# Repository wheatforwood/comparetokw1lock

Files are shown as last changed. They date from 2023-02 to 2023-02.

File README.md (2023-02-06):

A 3D printable lock that is compatible with mass-produced KW1 locks. It is accurate enough to interchange parts.

An SLA printer will be required to hit acceptable tolerances. You will need springs, top pins and bottom pins for your chambers. Finally, you will need a retaining clip to hold the plug in the bible and will most likly need to use a Q-Tip to clean excess resin from the top of the chamber via the access ports in the bottom of the bible. This model is for educational and prototyping purposes, it was not designed for field use. Use at your own risk!

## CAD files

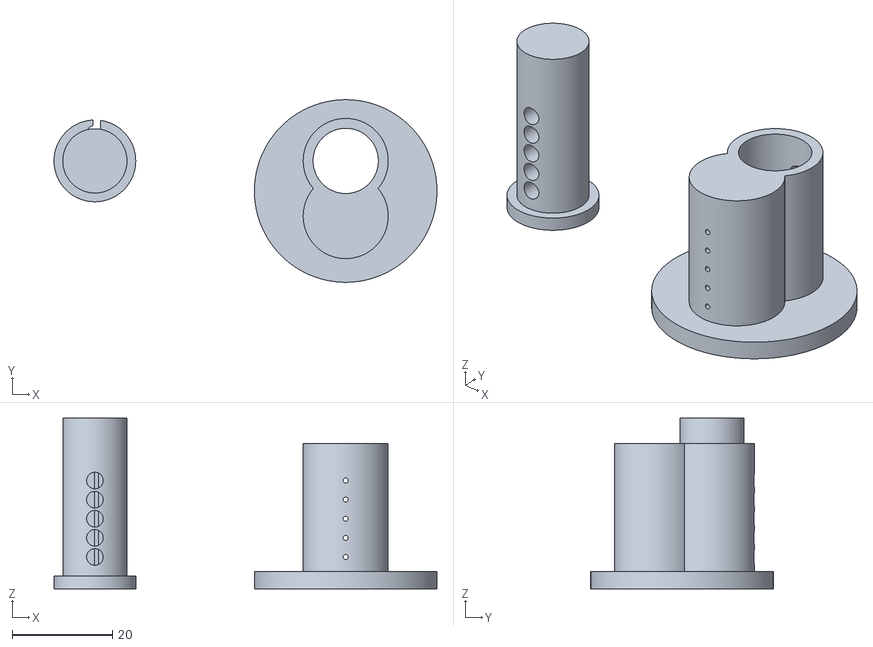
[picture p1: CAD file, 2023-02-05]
comparetokw1Lock.stl
76.3 x 36.4 x 34.0

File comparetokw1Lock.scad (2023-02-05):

$fn = 365;
// tollerance
$tol = 0.05;
// How many chambers are there in the lock to hold pins?
$number_chambers = 5;
// distance from 0 to the start of the first pin
$first_pin_offset = 6.34;
// distace between each pin chamber in the plug/bible
$chamber_dist = 3.81;
// the diameter of the chambers
$chamber_dia = 3.31;

$plug_diamater = 12.8;
$plug_rim_dia = $plug_diamater + 3.5;
$plug_length = 34;

$bible_thickness = 2;
$keyway_length =  28;
$keyway_height = 11.3;
$keyway_width = 3;
$keyway_offset_from_top_plug_rim = 5.5;

module compare_to_kw1_plug(){
    difference() {
        // additive
        union() {
            cylinder(d1=$plug_diamater, d2=$plug_diamater, h=$plug_length);
            cylinder(d1=$plug_rim_dia, d2=$plug_rim_dia, h=2.5);
        }
        
        //substractive
        union() {
            // chamber holes
            for ( i = [0 : ($number_chambers - 1)] ){
                translate([0,.80,($first_pin_offset + ($chamber_dist*i))]) {
                    rotate([90, 0 , 0]){
                        cylinder(d1=$chamber_dia, d2=$chamber_dia, h=30);
                    }
                }
            }
            // front concave
            translate([0,1.6,-11]){
                sphere(d=25);
            }
            
            //keyway
            // the .39 is a correction after printing and testing lock
            rotate([180,0,0]){
                translate([-$keyway_width/2, ( ($keyway_height * -1) + ($plug_rim_dia /2) +.39) - $keyway_offset_from_top_plug_rim, -$keyway_length]){
                        linear_extrude(height =$keyway_length) import("keyway.svg");
                }
            }
        }
    }
}

module compare_to_kw1_bible(){
    difference() {
        //additive
        union(){
            translate([0,-6,0]){
                cylinder(d1= 36.4, d2=36.4, h=3.4);
            }
            translate([0,0,3.3]){
                cylinder(d1=$plug_diamater+$tol+4.09, d2=$plug_diamater+$tol+4.09, $plug_length-8.3);
            }
            translate([0,-11,3.3]){
                cylinder(d1=$plug_diamater+$tol+4.09, d2=$plug_diamater+$tol+4.09, $plug_length-8.3);
            }
        }
        //subtractive
        union() {
            translate([9,-7.75,-2]){
            rotate([0, 0, 180]) {
            linear_extrude(height =2.5) resize([0,10,0], auto=true) import("WheatForWoodMark.svg");
            }
        }
            // chamber holes
            for ( i = [0 : ($number_chambers-1)] ){
                translate([0,.80,($first_pin_offset + ($chamber_dist*i))]) {
                    rotate([90, 0 , 0]){
                        cylinder(d1=$chamber_dia, d2=$chamber_dia, h=18.8);
                    }
                }
            }
            
            // vent holes for chambers (to prevent top pins getting stuck issue due to vacuum)
            for ( i = [0 : ($number_chambers - 1)] ){
                translate([0,.80,($first_pin_offset + ($chamber_dist*i))]) {
                    rotate([90, 0 , 0]){
                        cylinder(d1=1, d2=1, h=25);
                    }
                }
            }
            
            // access to chamber holes for excess resin cleaning (to prevent excess resin getting stuck in chambers then curing issue)
            for ( i = [0 : ($number_chambers - 1)] ){
                translate([0,10,($first_pin_offset + ($chamber_dist*i))]) {
                    rotate([90, 0 , 0]){
                        cylinder(d1=$chamber_dia, d2=$chamber_dia, h=$bible_thickness*2);
                    }
                }
            }
            // inset for plug
            translate([0,0,-0.05]){
                // The 0.15 below is a manual ajdument after a LOT of trial/error
                cylinder(d1=$plug_diamater+$tol+0.15, d2=$plug_diamater+$tol+0.15, h=$plug_length);
                cylinder(d1=$plug_diamater+4.6+$tol, d2=$plug_diamater+4.6+$tol, h=2.6+$tol);
            }
            
        }
    }
}


compare_to_kw1_plug();
translate([50, 0, 0]){
compare_to_kw1_bible();
}

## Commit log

2023-02-02 Fixes for top pins getting stuck in upper chambers
    [comparetokw1Lock.scad]
2023-02-02 STL for updates
    [comparetokw1Lock.stl]
2023-02-05 Changes to plug inset in Bible
    [comparetokw1Lock.scad, comparetokw1Lock.stl]
